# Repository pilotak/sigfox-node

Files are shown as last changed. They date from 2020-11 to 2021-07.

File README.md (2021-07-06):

# Sigfox temperature & humidity sensor



Outdoor battery powered temperature & humidity IOT sensor with integrated Sigfox transceiver and battery state monitor.

All data are sent to Sigfox backend, in order to save them to ie.: InfluxDB you can use  [Sigfox to InfluxDB convertor](https://github.com/pilotak/docker-sigfox-influxdb).

<p align="center">
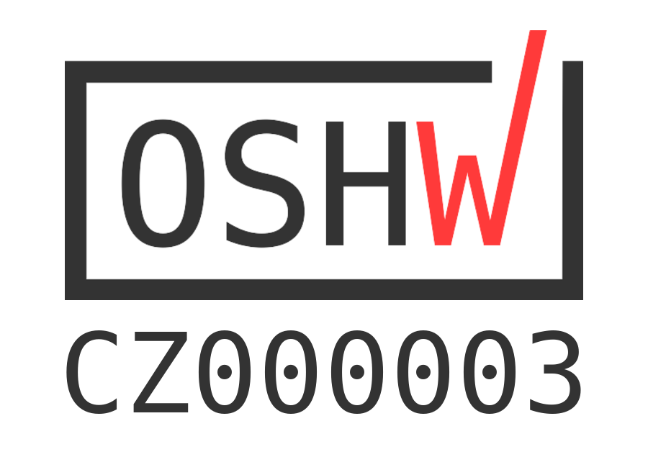
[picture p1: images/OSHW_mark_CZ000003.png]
  
</p>

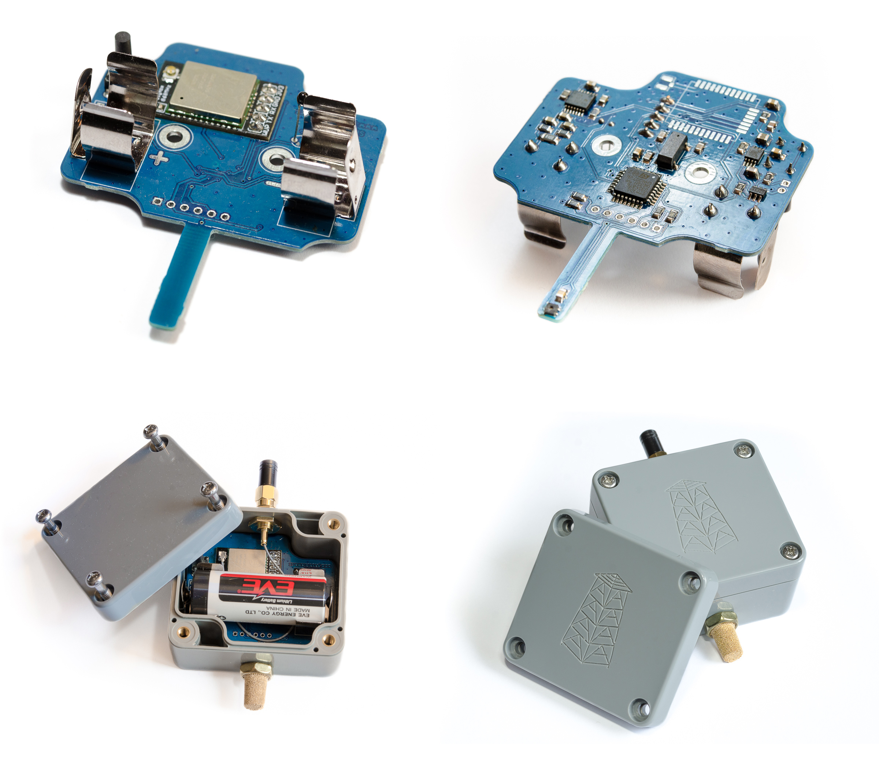
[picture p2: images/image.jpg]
Sigfox TH sensor


For more information please visit [wiki](./wiki)

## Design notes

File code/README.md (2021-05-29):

# Code
In order to compile the firmware you need to install:
- GCC ARM
- Python
- mbed-cli

## Compile
`mbed deploy` will automatically install mbed OS and following libraries
- https://github.com/pilotak/wisol
- https://github.com/pilotak/SHTC3
- https://github.com/pilotak/BQ35100

```sh
mbed deploy && mbed compile -m SIGFOX_TH_V1 -t GCC_ARM --profile release
```

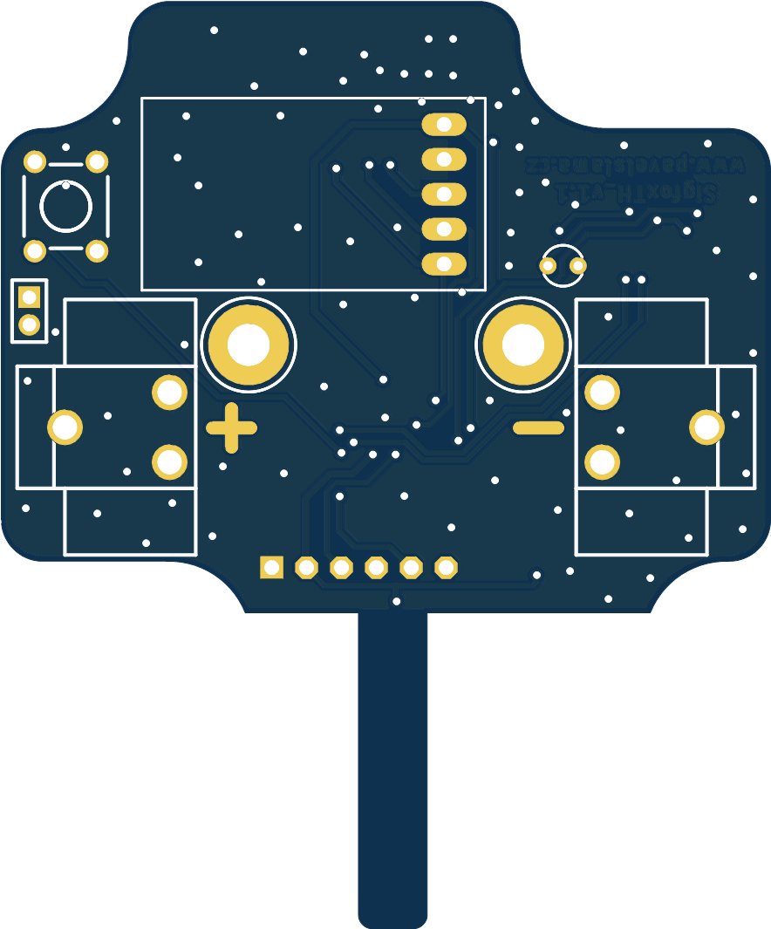
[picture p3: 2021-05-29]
images/board_top.png

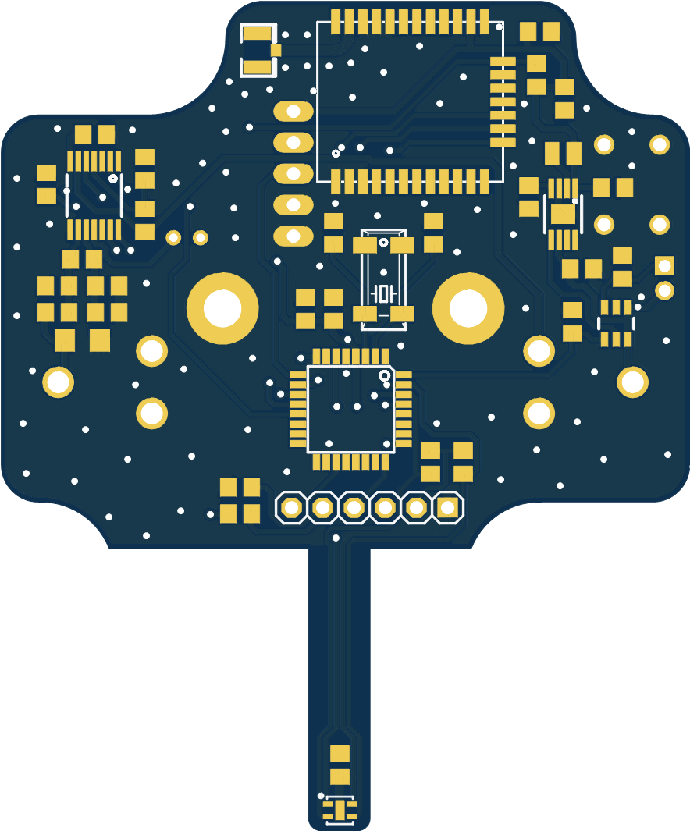
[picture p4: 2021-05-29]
images/board_bottom.png

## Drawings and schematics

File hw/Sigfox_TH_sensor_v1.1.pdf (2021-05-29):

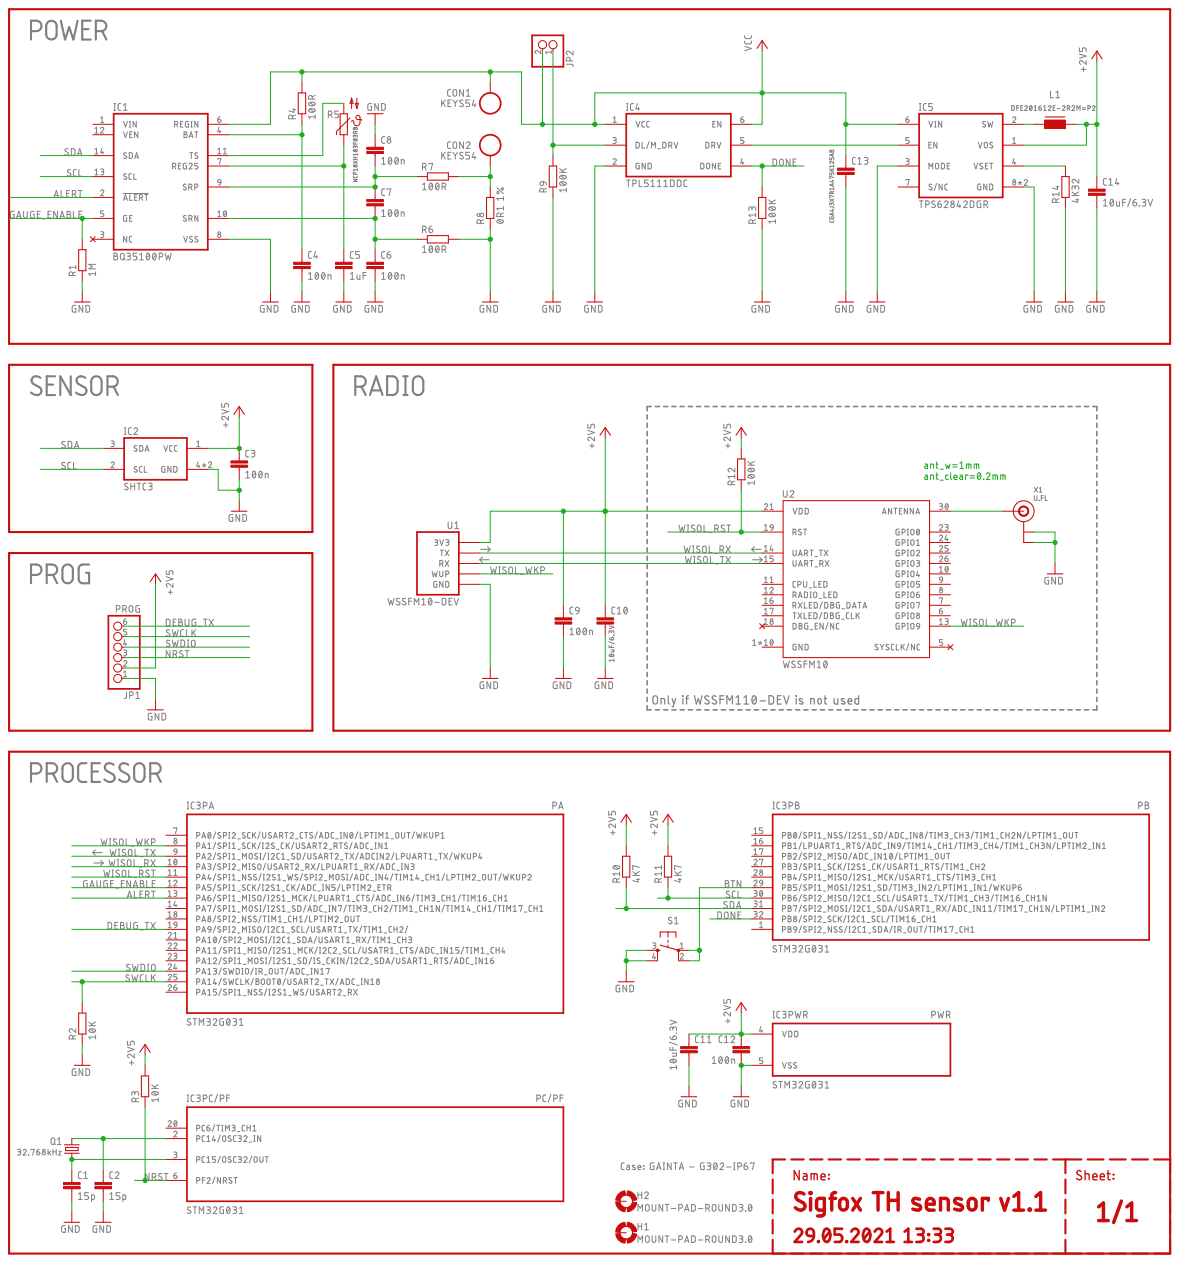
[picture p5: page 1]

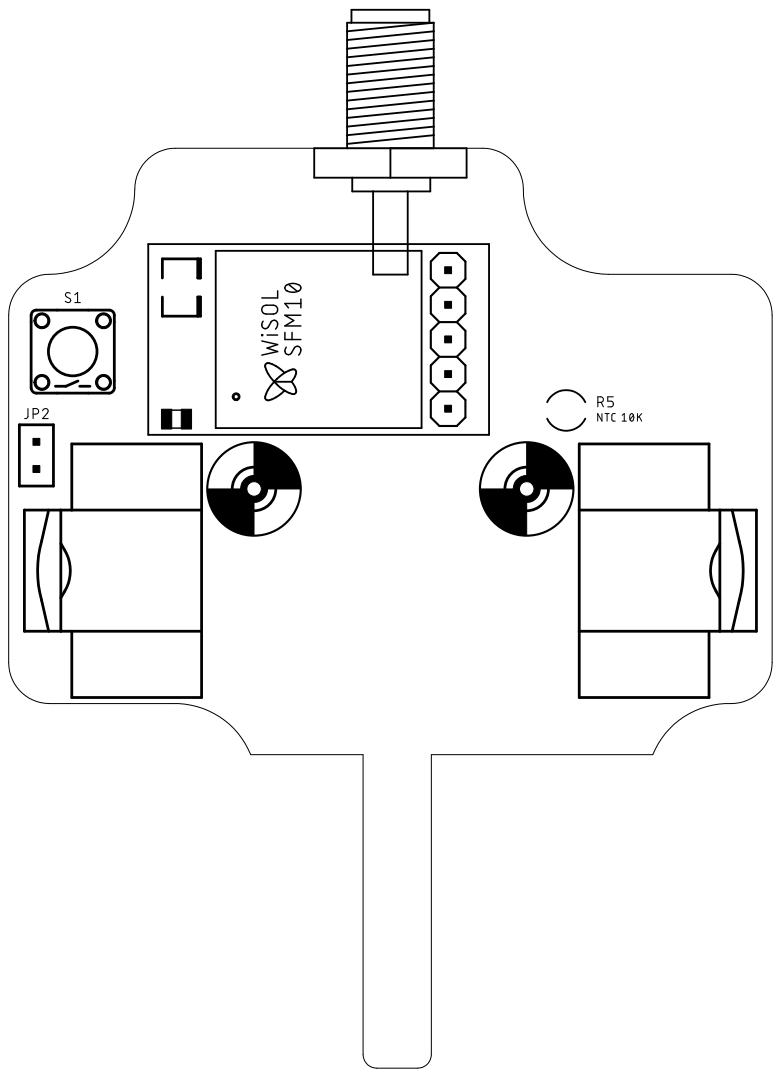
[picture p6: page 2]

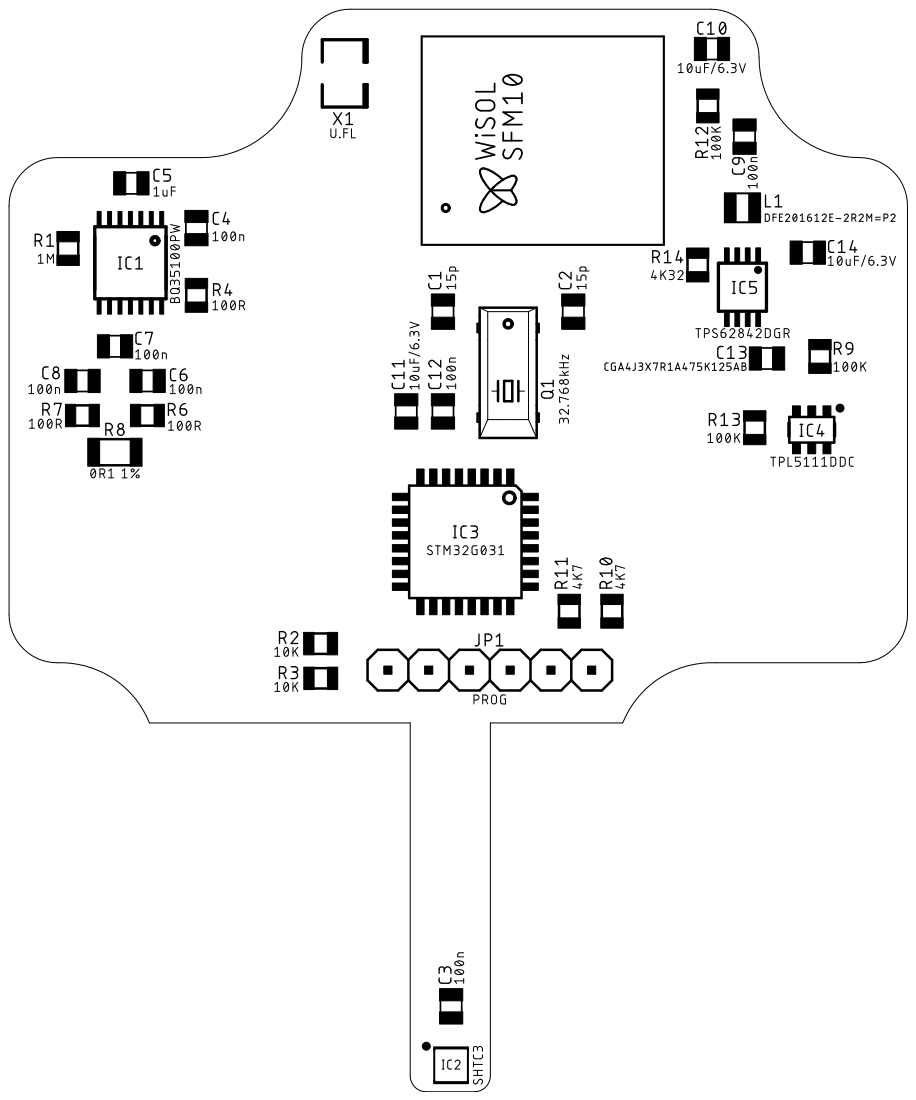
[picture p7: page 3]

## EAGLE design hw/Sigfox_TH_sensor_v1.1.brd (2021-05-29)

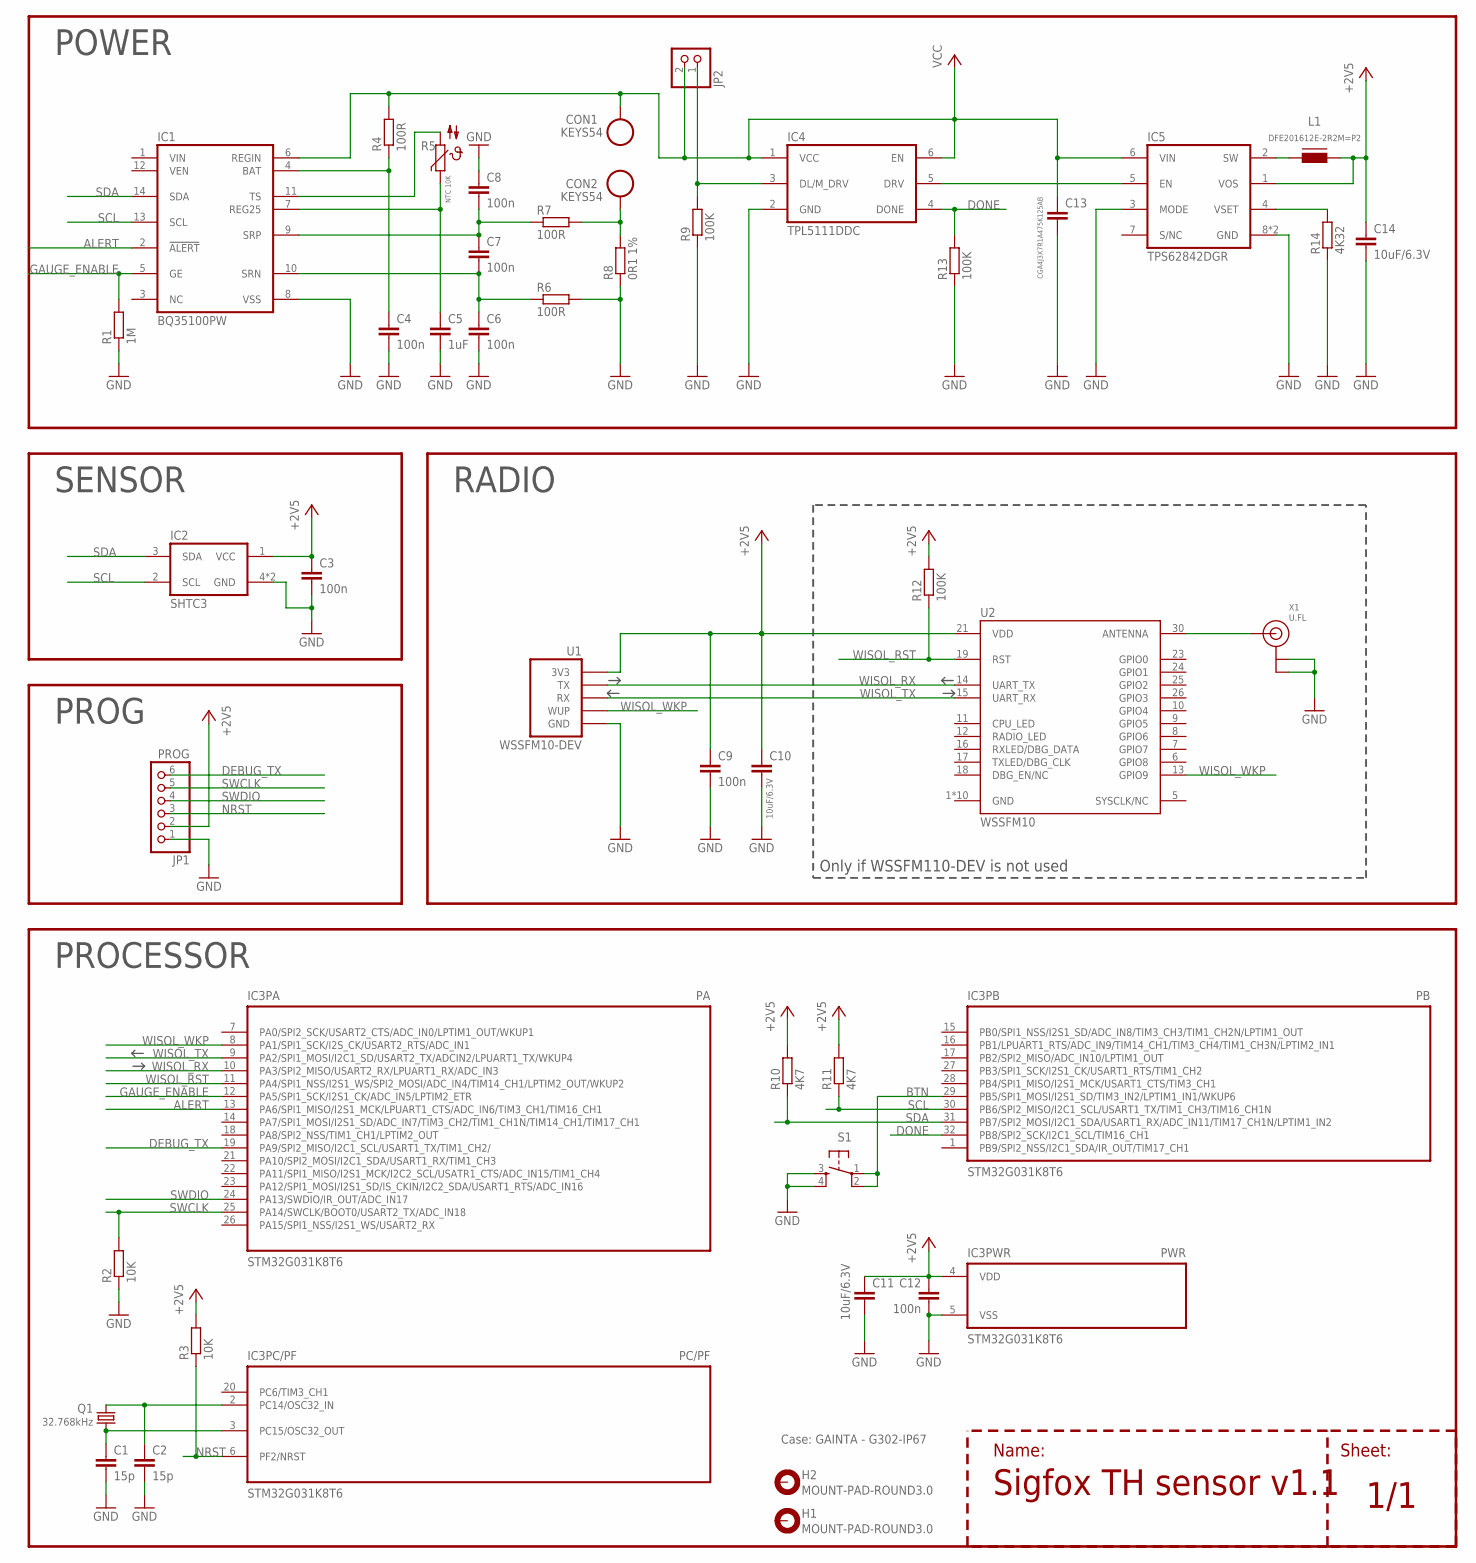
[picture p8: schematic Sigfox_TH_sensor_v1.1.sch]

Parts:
C1, C2: 15p; C0805
C3, C4, C6, C7, C8, C9, C12: 100n; C0805
C5: 1uF; C0805
C10, C11, C14: 10uF/6.3V; C0805
C13: CGA4J3X7R1A475K125AB; C0805
CON1, CON2: KEYS54
H1, H2: MOUNT-PAD-ROUND3.0; 3,0-PAD
IC1: BQ35100PW; TSSOP14
IC2: SHTC3; SON100P200X200X75-5T70X160N
IC3: STM32G031K8T6; TQFP32-08
IC4: TPL5111DDC; SOT23-6
IC5: TPS62842DGR; GHI-IC_MSOP-POWER.PAD-8(TI)
JP1: PROG; 1X06-S
JP2: PINHD-1X02_2.00; 1X02M
L1: DFE201612E-2R2M=P2; 0806
Q1: 32.768kHz; MM20SS
R1: 1M; R0805
R2, R3: 10K; R0805
R4, R6, R7: 100R; R0805
R5: NTC 10K; NTCM-HP
R8: 0R1 1%; R1206
R9, R12, R13: 100K; R0805
R10, R11: 4K7; R0805
R14: 4K32; R0805
S1: TACT_SWITCH-6X6X10-PTH; TACTILE-6X6-PTH
U1: WSSFM10-DEV
U2: WSSFM10
X1: U.FL

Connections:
+2V5: C3.1, C9.1, C10.1, C11.1, C12.1, C14.1, IC2.1 (VCC), IC3.4 (VDD), IC5.1 (VOS), JP1.2, L1.1, R3.2, R10.2, R11.2, R12.2, U1.3V3, U2.21 (VDD)
ALERT: IC1.2 (!ALERT!), IC3.13 (PA6/SPI1_MISO/I2S1_MCK/LPUART1_CTS/ADC_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)
BQ_2V5: C5.1, IC1.7 (REG25), R5.1
BTN: IC3.29 (PB5/SPI1_MOSI/I2S1_SD/TIM3_IN2/LPTIM1_I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), S1.1, S1.2
DEBUG_TX: IC3.19 (PA9/SPI2_MISO/I2C1_SCL/USART1_TX/TIM1_C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), JP1.6
DONE: IC3.32 (PB8/SPI2_SCK/I2C1_SCL/TIM16_CH1), IC4.4 (DONE), R13.2
GAUGE_ENABLE: IC1.5 (GE), IC3.12 (PA5/SPI1_SCK/I2S1_CK/ADC_IN5/LPTIM2_ETR), R1.2
GND: C1.2, C2.2, C3.2, C4.2, C5.2, C6.2, C8.1, C9.2, C10.2, C11.2, C12.2, C13.2, C14.2, IC1.8 (VSS), IC2.4 (GND), IC2.5 (GND), IC3.5 (VSS), IC4.2 (GND), IC5.3 (MODE), IC5.8 (GND), IC5.9 (GND), JP1.1, R1.1, R2.1, R6.2, R8.1, R9.1, R13.1, R14.1, S1.3, S1.4, U1.GND, U2.1 (GND), U2.2 (GND), U2.3 (GND), U2.4 (GND), U2.20 (GND), U2.22 (GND), U2.27 (GND), U2.28 (GND), U2.29 (GND), U2.31 (GND), X1.1 (GND), X1.2 (GND)
unnamed: IC5.4 (VSET), R14.2
unnamed: IC4.3 (DL/M_DRV), JP2.1, R9.2
unnamed: IC5.2 (SW), L1.2
unnamed: U2.30 (ANTENNA), X1.3 (SIGNAL)
unnamed: C1.1, IC3.3 (PC15/OSC32_OUT), Q1.4 (2)
unnamed: IC4.5 (DRV), IC5.5 (EN)
unnamed: C7.1, C8.2, IC1.9 (SRP), R7.1
unnamed: C6.1, C7.2, IC1.10 (SRN), R6.1
unnamed: C2.1, IC3.2 (PC14/OSC32_IN), Q1.1
unnamed: IC1.11 (TS), R5.2
unnamed: C4.1, IC1.4 (BAT), R4.1
NRST: IC3.6 (PF2/NRST), JP1.3, R3.1
PACK+: C13.1, CON1.1@0, CON1.1@1, CON1.1@2, IC1.6 (REGIN), IC4.1 (VCC), IC4.6 (EN), IC5.6 (VIN), JP2.2, R4.2
PACK-: CON2.1@0, CON2.1@1, CON2.1@2, R7.2, R8.2
SCL: IC1.13 (SCL), IC2.2 (SCL), IC3.30 (PB6/SPI2_MISO/I2C1_SCL/USART1_TX/TIM1_C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), R11.1
SDA: IC1.14 (SDA), IC2.3 (SDA), IC3.31 (PB7/SPI2_MOSI/I2C1_SDA/USART1_RX/ADC_IN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), R10.1
SWCLK: IC3.25 (PA14/SWCLK/BOOT0/USART2_TX/ADC_IN18), JP1.5, R2.2
SWDIO: IC3.24 (PA13/SWDIO/IR_OUT/ADC_IN17), JP1.4
WISOL_RST: IC3.11 (PA4/SPI1_NSS/I2S1_WS/SPI2_MOSI/ADC_IN4/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), R12.1, U2.19 (RST)
WISOL_RX: IC3.10 (PA3/SPI2_MISO/USART2_RX/LPUART1_RX/ADC_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), U1.TX, U2.14 (UART_TX)
WISOL_TX: IC3.9 (PA2/SPI1_MOSI/I2C1_SD/USART2_TX/ADCIN2/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), U1.RX, U2.15 (UART_RX)
WISOL_WKP: IC3.8 (PA1/SPI1_SCK/I2S_CK/USART2_RTS/ADC_IN1), U1.WUP, U2.13 (GPIO9)

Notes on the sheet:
Case: GAINTA - G302-IP67
POWER
Sigfox TH sensor v1.1
Sheet:
Name:
SENSOR
RADIO
Only if WSSFM110-DEV is not used
PROG
PROCESSOR

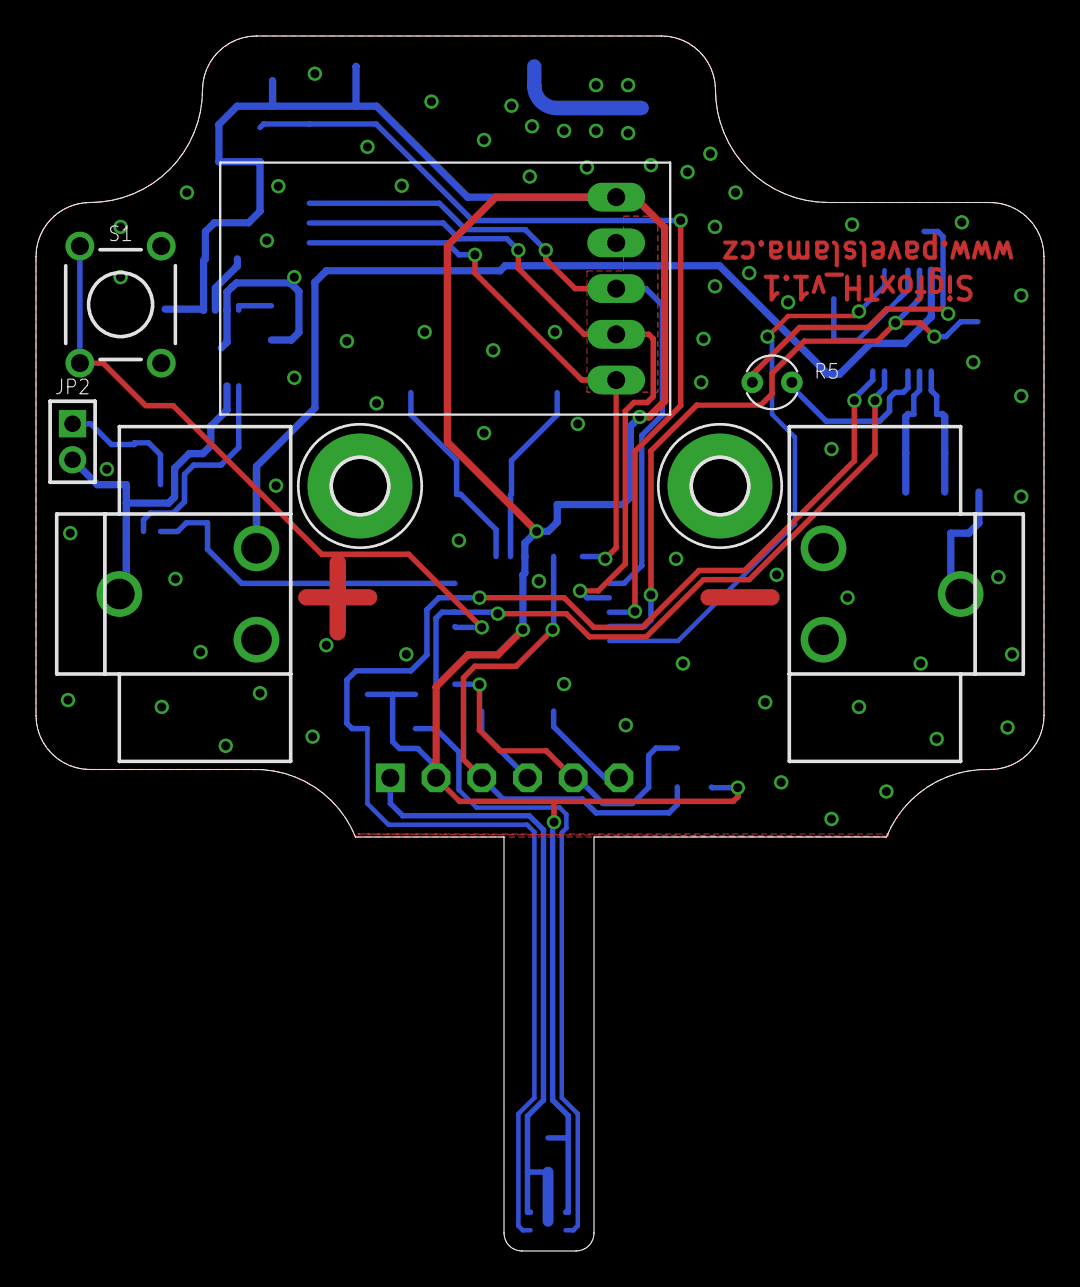
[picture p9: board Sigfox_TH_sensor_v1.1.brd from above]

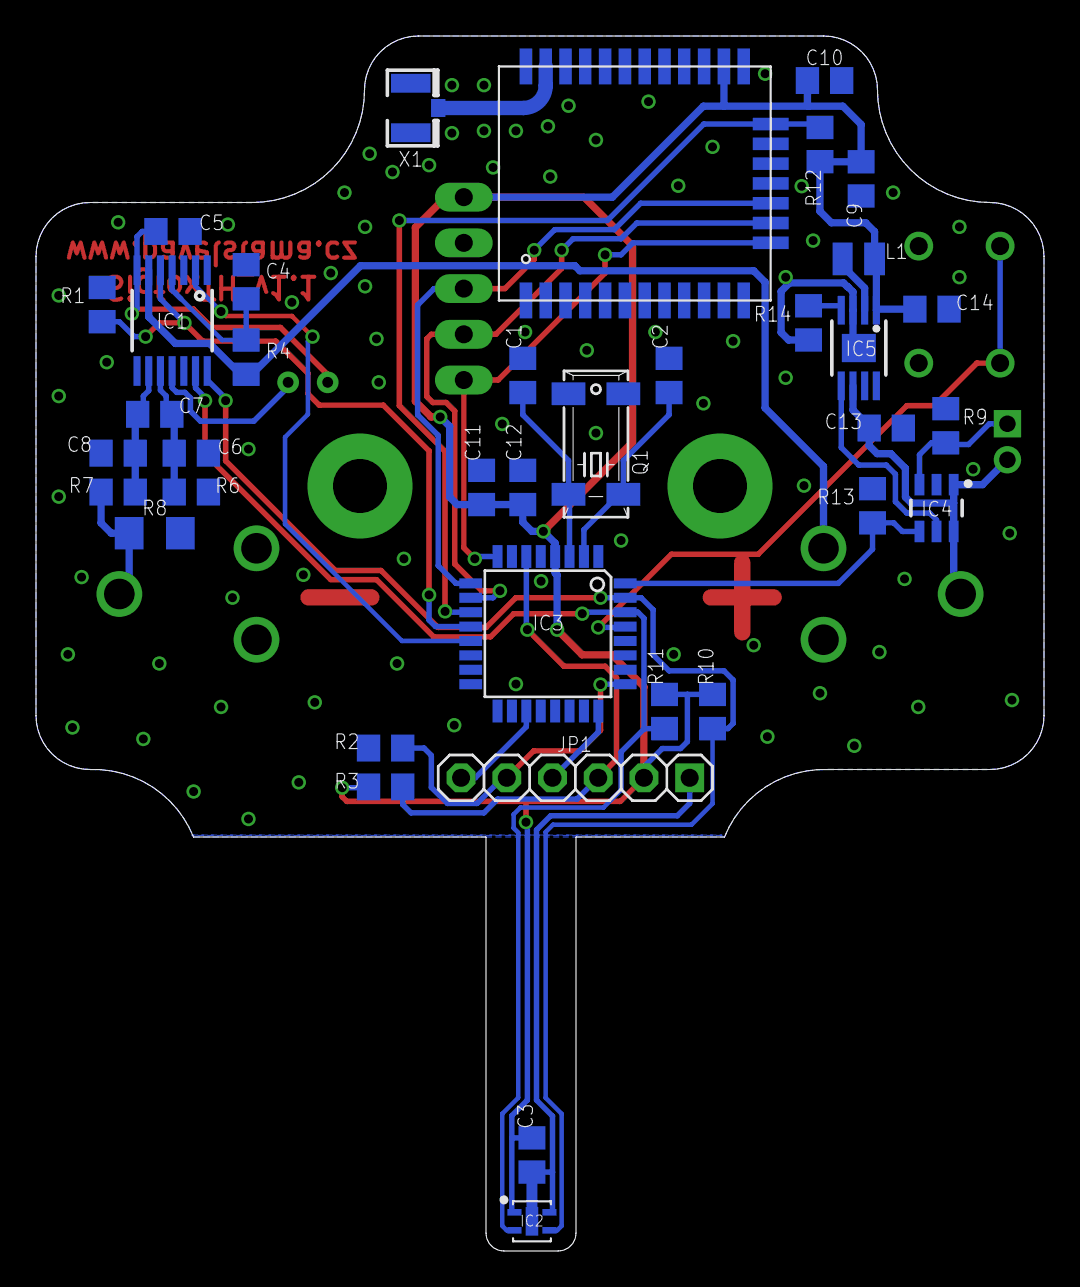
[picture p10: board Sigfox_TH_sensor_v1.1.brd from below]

Board: 2 copper layers, 56.0 x 67.5 mm, 46 parts (37 on the bottom side), 30 nets.

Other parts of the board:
CONN: SMA-PIGTAIL

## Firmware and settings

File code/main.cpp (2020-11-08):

#include "mbed.h"
#include "SHTC3.h"
#include "Wisol.h"
#include "BQ35100.h"

I2C i2c(I2C_SDA, I2C_SCL);
BQ35100 gauge(GAUGE_ENABLE_PIN);
DigitalIn button(USER_BUTTON, PullUp);
DigitalOut done(DONE_PIN, 0);

uint8_t temp = UCHAR_MAX;
uint8_t humidity = UCHAR_MAX;
uint8_t batt_percentage = UCHAR_MAX;

uint16_t round10(uint16_t number) {
    uint8_t rem = number % 10;
    return rem >= 5 ? (number - rem + 10) : (number - rem);
}

void readSensor() {
    SHTC3 sht;
    uint16_t raw_temp;
    uint16_t raw_humidity;

    if (!sht.init(&i2c)) {
        debug("SHT init failed\n");
        return;
    }

    if (!sht.read(&raw_temp, &raw_humidity, true)) { // low power mode
        debug("SHT read failed\n");
        return;
    }

    if (raw_temp < 1872) { // -40°C
        temp = 0;

    } else if (raw_temp > 39921) { // +61.6°C
        temp = 254;

    } else {
        // convert -40°C - +61.6°C to 0-254, math round one decimal place
        raw_temp = (((int32_t)raw_temp - 1872) * 2540) / (39921 - 1872);
        raw_temp = round10(raw_temp);
        temp = raw_temp / 10;
    }

    // convert 0-100% to 0-250, math round one decimal place
    raw_humidity = (uint32_t)raw_humidity * 2500 / 65535;
    raw_humidity = round10(raw_humidity);
    humidity = raw_humidity / 10;

    debug("Temperature: %u*C, humidity: %u%%\n", (temp * 4) - 400, humidity * 4);
}

void readBatteryPercentage() {
    if (!gauge.getRemainingPercentage(&batt_percentage)) {
        debug("Get batt remaining failed\n");
        return;
    }

    debug("Batt remaining: %u%%\n", batt_percentage);
}

void send() {
    // Initializing it this was is recommended due to a fact that underling UART instance
    // is destroyed once this function ends, therefore consumes less energy.
    Wisol wisol(WISOL_TX, WISOL_RX);
    uint8_t data[3];

    if (!wisol.init()) {
        debug("Wisol init failed\n");
        return;
    }

    debug("Sending: t: %02X, h: %02X, b: %02X\n", temp, humidity, batt_percentage);
    data[0] = temp;
    data[1] = humidity;
    data[2] = batt_percentage;

    if (wisol.sendFrame(data, sizeof(data))) {
        debug("Sent\n");

    } else {
        debug("Sending failed");
    }
}

int main() {
    bool button_state = (bool)button.read();
    button.mode(PullNone); // save energy

    i2c.frequency(400000); // speed up a little

    if (gauge.init(&i2c)) {
        if (button_state == false) {
            debug("Button is pressed\n");

            if (gauge.newBattery()) {
                debug("New battery set");

            } else {
                debug("New battery failed");
            }

            ThisThread::sleep_for(100ms);
        }

        if (gauge.startGauge()) {
            readSensor();
            readBatteryPercentage();
            send();

        } else {
            debug("Gauge enable failed\n");
        }

        gauge.disableGauge();

    } else {
        debug("Init gauge failed\n");
    }

    // let the timer know we are done
    for (auto i = 0; i < 2; i++) {
        done.write(1);
        ThisThread::sleep_for(2ms);
        done.write(0);
    }

    // We should not get here, but just in case
    ThisThread::sleep_for(rtos::Kernel::wait_for_u32_forever);
}

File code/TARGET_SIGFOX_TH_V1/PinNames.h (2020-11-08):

/* mbed Microcontroller Library
 * SPDX-License-Identifier: BSD-3-Clause
 ******************************************************************************
 *
 * Copyright (c) 2018 STMicroelectronics.
 * All rights reserved.
 *
 * This software component is licensed by ST under BSD 3-Clause license,
 * the "License"; You may not use this file except in compliance with the
 * License. You may obtain a copy of the License at:
 *                        opensource.org/licenses/BSD-3-Clause
 *
 ******************************************************************************
 */

#ifndef MBED_PINNAMES_H
#define MBED_PINNAMES_H

#include "cmsis.h"
#include "PinNamesTypes.h"

#ifdef __cplusplus
extern "C" {
#endif

typedef enum {
    ALT0  = 0x100,
    ALT1  = 0x200,
    ALT2  = 0x300,
    ALT3  = 0x400
} ALTx;

typedef enum {
    PA_0  = 0x00,
    PA_1  = 0x01,
    PA_1_ALT0 = PA_1 | ALT0,
    PA_2  = 0x02,
    PA_2_ALT0 = PA_2 | ALT0,
    PA_2_ALT1 = PA_2 | ALT1,
    PA_3  = 0x03,
    PA_3_ALT0 = PA_3 | ALT0,
    PA_3_ALT1 = PA_3 | ALT1,
    PA_4  = 0x04,
    PA_5  = 0x05,
    PA_6  = 0x06,
    PA_6_ALT0 = PA_6 | ALT0,
    PA_7  = 0x07,
    PA_7_ALT0 = PA_7 | ALT0,
    PA_7_ALT1 = PA_7 | ALT1,
    PA_7_ALT2 = PA_7 | ALT2,
    PA_8  = 0x08,
    PA_9  = 0x09,
    PA_9_ALT0 = PA_9 | ALT0,
    PA_10 = 0x0A,
    PA_10_ALT0 = PA_10 | ALT0,
    PA_11 = 0x0B,
    PA_12 = 0x0C,
    PA_13 = 0x0D,
    PA_14 = 0x0E,
    PA_14_ALT0 = PA_14 | ALT0,
    PA_15 = 0x0F,
    PA_15_ALT0 = PA_15 | ALT0,

    PB_0  = 0x10,
    PB_0_ALT0 = PB_0 | ALT0,
    PB_1  = 0x11,
    PB_1_ALT0 = PB_1 | ALT0,
    PB_1_ALT1 = PB_1 | ALT1,
    PB_2  = 0x12,
    PB_3  = 0x13,
    PB_4  = 0x14,
    PB_4_ALT0 = PB_4 | ALT0,
    PB_4_ALT1 = PB_4 | ALT1,
    PB_5  = 0x15,
    PB_5_ALT0 = PB_5 | ALT0,
    PB_5_ALT1 = PB_5 | ALT1,
    PB_6  = 0x16,
    PB_6_ALT0 = PB_6 | ALT0,
    PB_7  = 0x17,
    PB_8  = 0x18,
    PB_9  = 0x19,
    PB_10 = 0x1A,
    PB_11 = 0x1B,
    PB_12 = 0x1C,
    PB_13 = 0x1D,
    PB_13_ALT0 = PB_13 | ALT0,
    PB_14 = 0x1E,
    PB_14_ALT0 = PB_14 | ALT0,
    PB_15 = 0x1F,
    PB_15_ALT0 = PB_15 | ALT0,
    PB_15_ALT1 = PB_15 | ALT1,

    PC_0  = 0x20,
    PC_1  = 0x21,
    PC_2  = 0x22,
    PC_3  = 0x23,
    PC_4  = 0x24,
    PC_4_ALT0 = PC_4 | ALT0,
    PC_5  = 0x25,
    PC_5_ALT0 = PC_5 | ALT0,
    PC_6  = 0x26,
    PC_6_ALT0 = PC_6 | ALT0,
    PC_7  = 0x27,
    PC_7_ALT0 = PC_7 | ALT0,
    PC_8  = 0x28,
    PC_8_ALT0 = PC_8 | ALT0,
    PC_9  = 0x29,
    PC_9_ALT0 = PC_9 | ALT0,
    PC_10 = 0x2A,
    PC_10_ALT0 = PC_10 | ALT0,
    PC_11 = 0x2B,
    PC_11_ALT0 = PC_11 | ALT0,
    PC_12 = 0x2C,
    PC_13 = 0x2D,
    PC_14 = 0x2E,
    PC_15 = 0x2F,

    PD_0  = 0x30,
    PD_1  = 0x31,
    PD_2  = 0x32,
    PD_3  = 0x33,
    PD_4  = 0x34,
    PD_5  = 0x35,
    PD_6  = 0x36,
    PD_8  = 0x38,
    PD_9  = 0x39,

    PF_0  = 0x50,
    PF_1  = 0x51,

    // ADC internal channels
    ADC_TEMP = 0xF0,
    ADC_VREF = 0xF1,
    ADC_VBAT = 0xF2,

    // STDIO for console print
    STDIO_UART_TX = PA_9,
    STDIO_UART_RX = PA_10,

    USER_BUTTON = PB_5,

    WISOL_TX = PA_2_ALT0, // LowPower UART
    WISOL_RX = PA_3_ALT0,
    WISOL_RST_PIN = PA_4,
    WISOL_WKP_PIN = PA_1,

    GAUGE_ENABLE_PIN = PA_5,
    DONE_PIN = PB_8,

    // Standardized button names
    LED1 = PB_8,
    BUTTON1     = USER_BUTTON,
    SERIAL_TX   = STDIO_UART_TX,
    SERIAL_RX   = STDIO_UART_RX,
    USBTX       = STDIO_UART_TX,
    USBRX       = STDIO_UART_RX,
    I2C_SCL     = PB_6,
    I2C_SDA     = PB_7,
    SPI_MOSI    = PA_7,
    SPI_MISO    = PA_6,
    SPI_SCK     = PA_5,
    SPI_CS      = PB_0,
    PWM_OUT     = PB_3,

    /**** OSCILLATOR pins ****/
    RCC_OSC32_EN = PC_15,
    RCC_OSC32_IN = PC_14,
    RCC_OSC32_OUT = PC_15,
    RCC_OSC_EN = PC_15,
    RCC_OSC_IN = PC_14,

    /**** DEBUG pins ****/
    SYS_PVD_IN = PB_7,
    SYS_SWCLK = PA_14,
    SYS_SWDIO = PA_13,
    SYS_WKUP1 = PA_0,
    SYS_WKUP2 = PA_4,
    SYS_WKUP4 = PA_2,
    SYS_WKUP6 = PB_5,

    // Not connected
    NC = (int)0xFFFFFFFF
} PinName;

#ifdef __cplusplus
}
#endif

#endif

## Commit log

2020-11-04 update deps + calibration example
2020-11-04 calibration examples + lib update
2020-11-04 CI install ARM GCC 9-2019q4
2020-11-04 CI update ARM GCC install
2020-11-08 use 0.4bit gain for temperature & humidity
